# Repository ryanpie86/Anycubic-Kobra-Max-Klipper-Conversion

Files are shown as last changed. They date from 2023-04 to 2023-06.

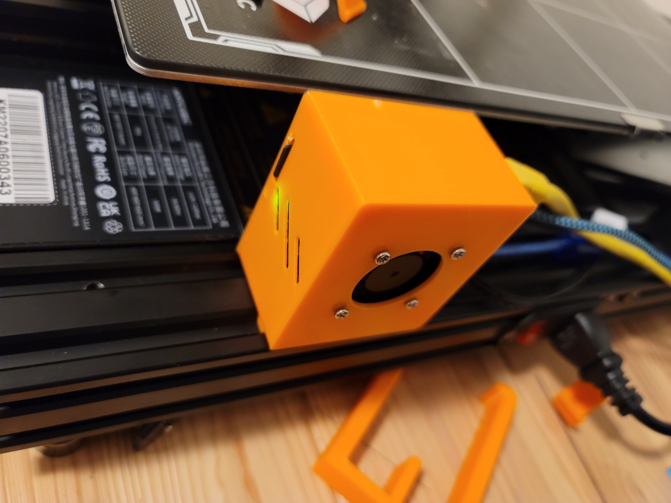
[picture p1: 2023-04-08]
20230408_024842.jpg

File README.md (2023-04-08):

# Anycubic-Kobra-Max-Klipper-Conversion

**You will need to remove resistor R66 on your circuit board and place it in R65 spot.**
**Please see https://www.reddit.com/r/anycubic/comments/ynvbj0/anycubic_kobra_working_config for detailed information**

The printer this has been configured for is stock minus just some Capricorn tubing (and of course the Klipper conversion)

I have tried to credit everyone for the information I have gathered in the printer.cfg. If you feel I have missed something, please do say so.

Also uploaded is a Cura project file containing my optimized 0.2 PLA+ slicer profile, and of course a Cali Cat sitting in it. Import the project into Cura as a new profile.

Oh, and no, your screen will not work after this. After you flash and get the 4 beeps the screen will freeze. Wait a few seconds, power the machine off, and then disconnect the screen. You won't be needing that where you're headed.

Join the discussion here: https://www.reddit.com/r/anycubic/comments/12a2fqp/any_interest_in_a_kobra_max_klipper_package/

This printer.cfg has print area mesh enabled by default. You just need to follow the steps outlined in the notes for the macro if you are using Cura, or follow the link contained to set up a different slicer.

From messing with it and the strain gauge, I found that the device Anycubic chose is inaccurate if not A) hot and B) heated at least to print temperature. There are two problems:
**
1. the extruder tension changes when the filament inside is cold/tugging on it while moving around

2. any little bit of solid plastic on the nozzle tip will ruin what you had previously set for z-offset after the mesh is complete.**

My config is optimized for this. You can home the printer cold just to get it ready if you want, but the START_PRINT macro makes up for it. It will heat, clear the mesh, re-home HOT, mesh the print area, then load the mesh and begin. I am getting very good results with this method so far, and have put quite a bit of time into making it work right. I've been able to set a hard z-offset and not play with it thus far.

Changed microsteps for X/Y to 64 as per invisiblek:

https://github.com/invisiblek/klipper_config/tree/kobraplus

This seems to have fixed Y axis layer shifting.

Added load/unload filament macros. Do not use these while printing, it will turn off your heaters and LEDs and change the temperature.

Added my model for an Orange Pi Zero 2 enclosure which will fit the frame rail behind the screen. This enclosure accomodates having a fan attached to the inside for a clean look.

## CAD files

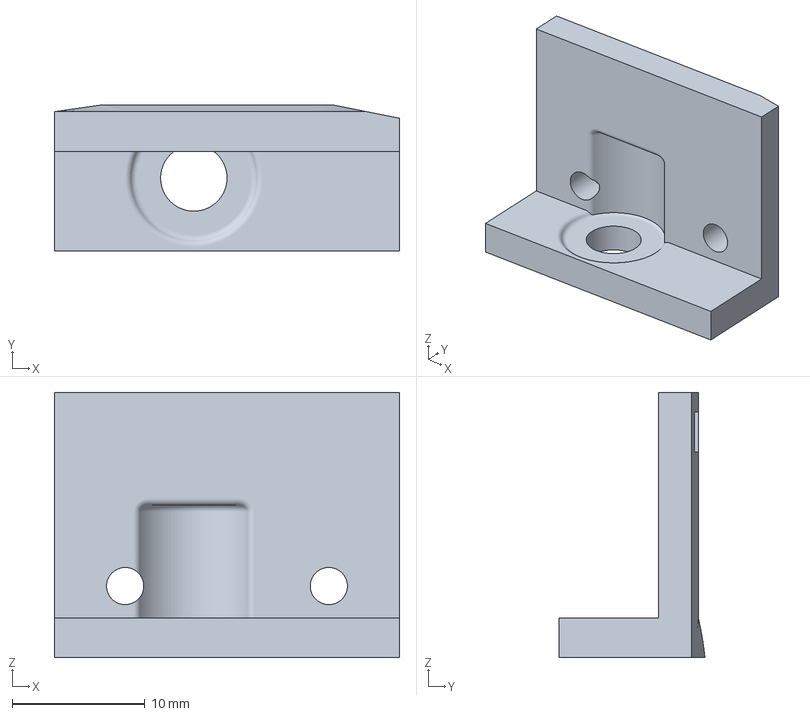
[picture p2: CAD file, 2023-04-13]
Kobra_ADXL345 v7.3mf
26.0 x 11.0 x 20.0 mm

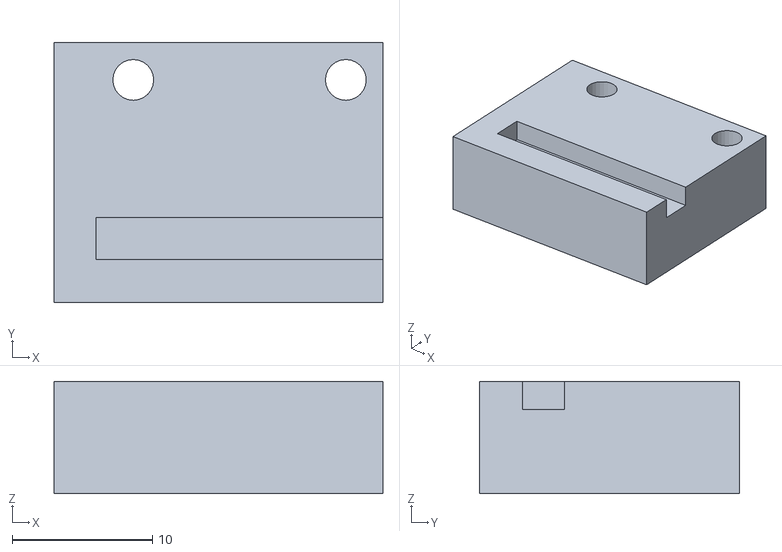
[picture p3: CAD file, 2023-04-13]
adxl345_bedPrint.stl
23.5 x 18.5 x 8.00

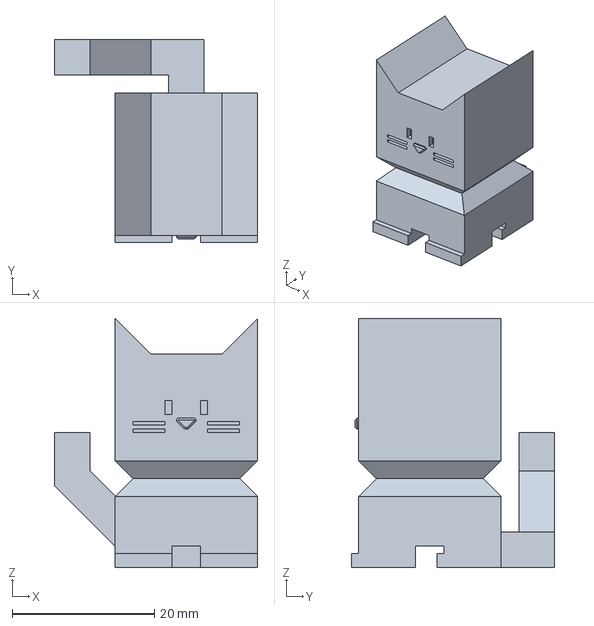
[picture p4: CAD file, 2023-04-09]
AKMAX_calicat.3mf
28.5 x 28.5 x 35.0 mm

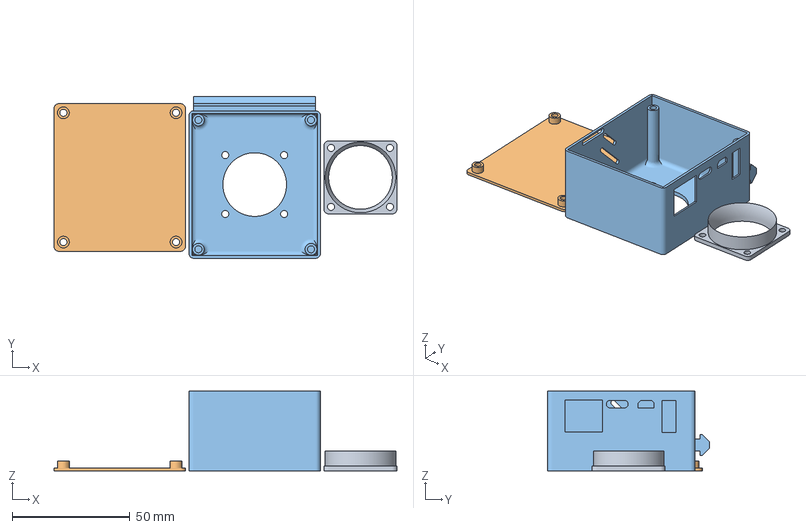
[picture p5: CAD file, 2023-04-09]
oPiZero2EnclosureWithFanShroud.3mf
145.6 x 68.6 x 33.8 mm
OrangePi_Zero_2 v14_dwg v13.3mf
oPiBottomCover.3mf
oPiTopCover.3mf

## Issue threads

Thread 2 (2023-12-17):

Start_macro doesnt start the print after calibration

namalahideaway, 2023-12-17:
The start_macro calibrates and then print is paused. You need to manually resume the print once the calibration is done.

Have cura python and start macro enabled.

not sure what the issue is.

If i use defauly cura macro it works... but using the start_macro in the macros.cfg it pauses.

ryanpie86, 2023-12-17:
It pauses to purge and clean the nozzle. You can remove the pause line from
the start_print macro in macros.cfg.

On Sat, Dec 16, 2023, 9:31 PM namalahideaway ***@***.***>
wrote:

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

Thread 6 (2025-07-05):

Current for the Z steppers

50koruny, 2025-07-05:
Good job.Thank you for this.
It helped me a lot.
Anyway, there is a 0.9A current for the Z stepper driver.
There are two steppers connected to that driver in parallel connection, so with 0.9A, every stepper will only get 0,45A of current, which is low.
I just wanted to say this...
But overally, this config is a good reference to get Klipper to Kobra Max.

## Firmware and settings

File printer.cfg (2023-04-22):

## Anycubic Kobra Max ##
## Compile for HC32F460 ##
## Serial PA3 & PA2 "Anycube"

[include mainsail.cfg]
[include macros.cfg]

[mcu]
serial: /dev/serial/by-id/usb-1a86_USB_Serial-if00-port0
restart_method: command
baud: 250000

### Enable this to use the Orange Pi as MCU.
### I haven't found anything useful for this yet as nothing works for SPI on it
#[mcu opi]
#serial: /tmp/klipper_host_mcu

### Enable this to use an RP2040 for your ADXL host. You cannot use the Orange Pi so this is the next best option.
#[mcu adxl]
# Change <mySerial> to whatever you found above. For example,
# usb-Klipper_rp2040_E661640843545B2E-if00
#serial: /dev/serial/by-id/usb-Klipper_rp2040_E660C062137B4E29-if00
#[adxl345]
#cs_pin: adxl:gpio1
#spi_bus: spi0a
#axes_map: x,z,y
#[resonance_tester]
#accel_chip: adxl345
#    203.5, 200, 20
#[output_pin power_mode] # Improve power stability
#pin: adxl:gpio23

[stepper_x]
step_pin: PA5
dir_pin: PA4
enable_pin: !PC3
microsteps: 64
rotation_distance: 40
endstop_pin: !PA6
position_min: -6
position_endstop: -5
position_max: 407
homing_speed: 100

[tmc2209 stepper_x]
uart_pin:PA15
tx_pin:PA9
#diag_pin:PA6
sense_resistor: 0.100
run_current: 0.9
uart_address: 3
#driver_SGTHRS: 0
interpolate: False
stealthchop_threshold: 999999

[stepper_y]
step_pin: PC4
dir_pin: PA7
enable_pin: !PC3
microsteps: 64
rotation_distance: 40
endstop_pin: !PC5
position_min: -23.3
position_endstop: -23.2
position_max: 400
homing_speed: 100

[tmc2209 stepper_y]
uart_pin:PA15
tx_pin:PA9
#diag_pin:^PC5
sense_resistor: 0.100
run_current: 1
uart_address: 1
#driver_SGTHRS: 50
interpolate: False
#stealthchop_threshold: 999999

### Don't forget to SET YOUR E-STEPS!
### Measure 120mm, then extrude 100mm
### G1 E100 F100
### step_distance = old_e_steps * ((120 - distance_to_mark) / 100)

[extruder]
max_extrude_only_distance: 100.0
step_pin: PC14
dir_pin: !PC15
enable_pin: !PC3
microsteps: 16
#rotation_distance: 7.71 #For stock extruder (To be calibrated !)
rotation_distance: 7.21
nozzle_diameter: 0.800
filament_diameter: 1.750
heater_pin: PA1
sensor_type: EPCOS 100K B57560G104F
sensor_pin: PC1
min_temp: 0
max_temp: 250
pressure_advance: 0.6

[tmc2208 extruder]
uart_pin:PA15
tx_pin:PA9
#diag_pin:PB7
sense_resistor: 0.100
run_current: 0.9
uart_address: 0
#stealthchop_threshold: 999999

[stepper_z]
step_pin: PC7
dir_pin: !PC6
enable_pin: !PC3
microsteps: 16
rotation_distance: 8
endstop_pin: probe:z_virtual_endstop
#endstop_pin: PA8
#position_endstop: 0
position_min: -20
position_max: 452
homing_speed: 5

[tmc2209 stepper_z]
uart_pin:PA15
tx_pin:PA9
#diag_pin:PA8
sense_resistor: 0.100
run_current: 0.9
uart_address: 2
#driver_SGTHRS: 0
stealthchop_threshold: 999999

[stepper_z1]
step_pin: PB1
dir_pin: !PB0
enable_pin: !PC3
microsteps: 16
rotation_distance: 8

[probe]
pin: !PB6
speed: 2.5
samples: 3
samples_tolerance_retries: 3
#z_offset: 0.05
activate_gcode: probe_reset
### This macro is needed to reset the factory strain gauge on the Kobra Max
[gcode_macro probe_reset]
gcode:
    SET_PIN PIN=probe_reset_pin VALUE=1
    G4 P500
    SET_PIN PIN=probe_reset_pin VALUE=0
    G4 P100

[output_pin probe_reset_pin]
pin: !PB7

[safe_z_home]
home_xy_position: 203.5, 200 # Center of bed
speed: 100
z_hop: 5               # Move up 5mm
z_hop_speed: 20
move_to_previous: False

[bed_mesh]
speed: 100
horizontal_move_z: 3
mesh_min: 19, 19
mesh_max: 380, 380
algorithm: bicubic
probe_count: 5, 5

[output_pin LED]
pin: mcu:PB8
pwm: False
value: 0

[heater_bed]
heater_pin: PA0
sensor_type: EPCOS 100K B57560G104F
sensor_pin: PC0
#control = pid
#pid_kp = 73.966
#pid_ki = 0.884
#pid_kd = 1547.747
min_temp: 0
max_temp: 130

[fan]
pin: PB9

[heater_fan hotend_fan]
pin: PA13
heater: extruder
heater_temp: 50.0

[heater_fan controller_fan]
pin: PA14
heater: heater_bed
heater_temp: 45.0

[filament_switch_sensor runout]
pause_on_runout: True
switch_pin: !PC13

[temperature_sensor pi_temp]
sensor_type: temperature_host
min_temp: 0
max_temp: 100

[printer]
kinematics: cartesian
max_velocity: 300
max_accel: 2500
max_z_velocity: 5
max_z_accel: 100


#*# <---------------------- SAVE_CONFIG ---------------------->
#*# DO NOT EDIT THIS BLOCK OR BELOW. The contents are auto-generated.
#*#
#*# [heater_bed]
#*# control = pid
#*# pid_kp = 69.538
#*# pid_ki = 0.893
#*# pid_kd = 1353.388
#*#
#*# [extruder]
#*# control = pid
#*# pid_kp = 28.130
#*# pid_ki = 1.875
#*# pid_kd = 105.487
#*#
#*# [probe]
#*# z_offset = -0.110
#*#
#*# [input_shaper]
#*# shaper_type_x = mzv
#*# shaper_freq_x = 68.2
#*# shaper_type_y = mzv
#*# shaper_freq_y = 33.4

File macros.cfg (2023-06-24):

[gcode_macro LOAD_FILAMENT]
gcode:
    SET_HEATER_TEMPERATURE HEATER=extruder TARGET=210
    M109 S210
    SET_PIN PIN=LED VALUE=1.00
    M83
    G0 E10 F60
    M83
    G0 E100 F600
    M83
    G0 E100 F600
    SET_HEATER_TEMPERATURE HEATER=extruder TARGET=210
    M83
    G0 E100 F300
    M83
    G0 E100 F300
    SET_HEATER_TEMPERATURE HEATER=extruder TARGET=210
    M83
    G0 E100 F300
    M83
    G0 E100 F300
    SET_HEATER_TEMPERATURE HEATER=extruder TARGET=0
    SET_PIN PIN=LED VALUE=0.00

[gcode_macro UNLOAD_FILAMENT]
gcode:
    M109 S210
    SET_PIN PIN=LED VALUE=1.00
    M83
    G0 E-50 F60
    M83
    G0 E-50 F300
    M83
    G0 E-100 F600
    M83
    G0 E-100 F600
    M83
    G0 E-100 F600
    M83
    G0 E-100 F600
    TURN_OFF_HEATERS
    SET_PIN PIN=LED VALUE=0.00

#     In CURA use the following machine Start GCODE:
#
#     START_PRINT EXTRUDER_TEMP={material_print_temperature_layer_0} BED_TEMP={material_bed_temperature_layer_0} AREA_START=%MINX%,%MINY% AREA_END=%MAXX%,%MAXY%
#
#     If you want to edit your Start Print GCODE, do it in this configuration instead.

[gcode_macro START_PRINT]
gcode:
    G28; Home
    G1 X1 Y1 Z1; go to center while heating up
    G1 Z0.1 F600; lower Z to bed so blob will stick to it
    {% set BED_TEMP = params.BED_TEMP|default(60)|float %}
    {% set EXTRUDER_TEMP = params.EXTRUDER_TEMP|default(190)|float %}
    # Start bed heating (but don't wait for it)
    M140 S{BED_TEMP}
    # Use absolute coordinates
    G90
    # Wait for bed to reach temperature
    M190 S{BED_TEMP}
    # Set and wait for nozzle to reach temperature
    M109 S{EXTRUDER_TEMP}
    BED_MESH_CLEAR
    BED_MESH_PROFILE REMOVE="default"
    G28 Z; recalibrate Z now that we are at temp
    Z_TILT_ADJUST
    BED_MESH_CALIBRATE AREA_START={params.AREA_START|default("0,0")} AREA_END={params.AREA_END|default("0,0")}
    BED_MESH_PROFILE LOAD="default"
    PAUSE
    SET_PIN PIN=LED VALUE=1.00
    G0 E25 F2700; spit out a pile of goo into the corner

###     In CURA use the following machine End GCODE:
###
#     END_PRINT
###
###     If you want to edit your End Print GCODE, do it in this configuration instead.

[gcode_macro END_PRINT]
gcode:
    G91
    #turn off heaters
    M106 S0
    M104 S0
    M140 S0
    G0 E-7 F2700; retract 7mm
    G1 E-2 Z0.2 F2400; retract 2mm more and raise Z by one layer
    G1 X5 Y5 F3000; move over 5mm for a wipe
    G1 Z10; raise Z by 10
    G90
    G1 X10 Y400; present the print
    M84 X Y E; turn off all the steppers but Z
    #turn off the light
    SET_PIN PIN=LED VALUE=0.00

[gcode_macro DO_A_MESH]
gcode:
    #unload the existing mesh profile
    BED_MESH_CLEAR
    M140 S60; PREHEAT bed
    M109 S175; PREHEAT nozzle
    #clear the existing mesh out 
    BED_MESH_PROFILE REMOVE="default"
    M190 S60;  Wait for bed to reach temperature
    M109 S215; Set and wait for nozzle to reach temperature
    G28; home axes
    Z_TILT_ADJUST
    #perform a standard full-bed mesh level
    BED_MESH_CALIBRATE_BASE


### This macro is to mesh only the area of the bed which will be printed on
### In order to take advantage of this option, there is further work you will need to do in your slicer software
### If you do not use Cura, please visit the following link to finish setting this up:
#
#                 https://gist.github.com/ChipCE/95fdbd3c2f3a064397f9610f915f7d02
#
### If you DO use Cura, I have already taken most steps for you. Please visit the following link to download the post processing plugin. Save this text as KlipperPrintArea.py.
#
#                 https://raw.githubusercontent.com/ChipCE/Slicer-profile/master/cura-slicer/scripts/KlipperPrintArea.py
#
### In cura menu Help -> Show configuration folder. - Copy the python script from the above link in to scripts folder. - Restart Cura - In cura menu Extensions ->
### Post processing -> Modify G-Code and select Klipper print area mesh


[gcode_macro BED_MESH_CALIBRATE]
rename_existing: BED_MESH_CALIBRATE_BASE
; gcode parameters
variable_parameter_AREA_START : 0,0
variable_parameter_AREA_END : 0,0
; the clearance between print area and probe area 
variable_mesh_area_offset : 5.0
; number of sample per probe point
variable_probe_samples : 2
; minimum probe count
variable_min_probe_count : 4
; scale up the probe count, should be 1.0 ~ < variable_max_probe_count/variable_min_probe_count
variable_probe_count_scale_factor : 1.0
; enable preference index
variable_enable_reference_index : False
gcode:
    {% if params.AREA_START and params.AREA_END %}
        {% set bedMeshConfig = printer["configfile"].config["bed_mesh"] %}
        {% set safe_min_x = bedMeshConfig.mesh_min.split(",")[0]|float %}
        {% set safe_min_y = bedMeshConfig.mesh_min.split(",")[1]|float %}
        {% set safe_max_x = bedMeshConfig.mesh_max.split(",")[0]|float %}
        {% set safe_max_y = bedMeshConfig.mesh_max.split(",")[1]|float %}

        {% set area_min_x = params.AREA_START.split(",")[0]|float %}
	{% set area_min_y = params.AREA_START.split(",")[1]|float %}
	{% set area_max_x = params.AREA_END.split(",")[0]|float %}
	{% set area_max_y = params.AREA_END.split(",")[1]|float %}

	{% if bedMeshConfig.probe_count.split(",")|length == 2 %}
            {% set meshPointX = bedMeshConfig.probe_count.split(",")[0]|int %}
            {% set meshPointY = bedMeshConfig.probe_count.split(",")[1]|int %}
        {% else %}
            {% set meshPointX = bedMeshConfig.probe_count.split(",")[0]|int %}
            {% set meshPointY = bedMeshConfig.probe_count.split(",")[0]|int %}
        {% endif %}

	{% set meshMaxPointX = meshPointX %}
	{% set meshMaxPointY = meshPointY %}


        {% if (area_min_x < area_max_x) and (area_min_y < area_max_y) %}
            {% if area_min_x - mesh_area_offset >=  safe_min_x %}
                {% set area_min_x = area_min_x - mesh_area_offset %}
            {% else %}
                {% set area_min_x = safe_min_x %}
            {% endif %}

            {% if area_min_y - mesh_area_offset >=  safe_min_y %}
                {% set area_min_y = area_min_y - mesh_area_offset %}
            {% else %}
                {% set area_min_y = safe_min_y %}
            {% endif %}

            {% if area_max_x + mesh_area_offset <=  safe_max_x %}
                {% set area_max_x = area_max_x + mesh_area_offset %}
            {% else %}
                {% set area_max_x = safe_max_x %}
            {% endif %}

            {% if area_max_y + mesh_area_offset <=  safe_max_y %}
                {% set area_max_y = area_max_y + mesh_area_offset %}
            {% else %}
                {% set area_max_y = safe_max_y %}
            {% endif %}

            {% set meshPointX = (meshPointX * (area_max_x - area_min_x) / (safe_max_x - safe_min_x) * probe_count_scale_factor)|round(0)|int %}
            {% if meshPointX < min_probe_count %}
                {% set meshPointX = min_probe_count %}
            {% endif %}
	    {% if meshPointX > meshMaxPointX %}
                {% set meshPointX = meshMaxPointX %}
            {% endif %}

            {% set meshPointY = (meshPointY * (area_max_y -area_min_y ) / (safe_max_y - safe_min_y) * probe_count_scale_factor )|round(0)|int %}
            {% if meshPointY < min_probe_count %}
                {% set meshPointY = min_probe_count %}
            {% endif %}
	    {% if meshPointY > meshMaxPointY %}
                {% set meshPointY = meshMaxPointY %}
            {% endif %}

            {% set algorithm = "bicubic" %}
	    {% if "algorithm" in bedMeshConfig %}
	        {% set algorithm = bedMeshConfig.algorithm %}
            {% endif %}
            {% if meshPointX >=7 or meshPointY >=7 %}
                {% set algorithm = "bicubic" %}
            {% endif %}

            {% if enable_reference_index %}
                {% set referenceIndex = (meshPointX * meshPointY / 2 - 1 )|round(0)|int %}
                BED_MESH_CALIBRATE_BASE mesh_min={area_min_x},{area_min_y} mesh_max={area_max_x},{area_max_y} probe_count={meshPointX},{meshPointY} samples={probe_samples|int} algorithm={algorithm} relative_reference_index={referenceIndex}
            {% else %}
                BED_MESH_CALIBRATE_BASE mesh_min={area_min_x},{area_min_y} mesh_max={area_max_x},{area_max_y} probe_count={meshPointX},{meshPointY} samples={probe_samples|int} algorithm={algorithm}
            {% endif %}
        {% else %}
            BED_MESH_CALIBRATE_BASE
        {% endif %}
    {% else %}
        BED_MESH_CALIBRATE_BASE
    {% endif %}
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

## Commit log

2023-04-04 Add files via upload
    Compiled 3 April 2023 using Klipper v0.11.0-159-gfec7ddd8
2023-04-04 Add files via upload
    Current Cura 5.3.0 profile for 0.2 layer PLA+. File also includes a Cali Cat (https://www.thingiverse.com/thing:1545913)
    [AKMAX_calicat.3mf]
2023-04-04 Update printer.cfg
    Disabled stealthchop for Z to troubleshoot some TMC temperature errors
    Increased X/Y min by -0.1 to avoid out of range error when homing
    [printer.cfg]
2023-04-04 Update printer.cfg
    Reorganized some things, fixed an odd error where Z would not home if M84 happens above ~10mm high.
    [printer.cfg]
2023-04-04 Update printer.cfg
    Work on START_PRINT and attempt to get rid of blob
    [printer.cfg]
2023-04-05 https://github.com/invisiblek/klipper_config/tree/kobraplus
    Change interpolation values and microsteps for X/Y, disable stealthchop. Please see link for more information. Am currently experiencing severe Y axis shift.
    [printer.cfg]
2023-04-06 https://ellis3dp.com/Print-Tuning-Guide/articles/determining_max_speeds_accels.html
    Losing steps w/ 150@5000, iffy at 200/4000, so settled on 150/4000. I doubt this printer is ever going to hit 150mm/s speed anyway. The bed is just far too heavy.
    [printer.cfg]
2023-04-08 Update printer.cfg
    Added load and unload filament macros to simulate factory controls, only better. You don't need to keep an eye on it. Press the button and it will wait to heat (to a much lower temperature), turn on 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
    [printer.cfg]
2023-04-09 Update printer.cfg
    Pressure advance and basic resonance compensation working. Orange Pi Zero MCU working but still no SPI for ADXL. Will have to do a Pico for this. Increased Y current to 1.0
    [printer.cfg]
2023-04-13 Update printer.cfg
    Clean up cfg, add ADXL information and the resonances for my particular printer. Make separate file for macros because they were crowding the cfg.
    [printer.cfg]
2023-04-13 Add files via upload
    All of the macros I use
    [macros.cfg]
2023-04-13 Add files via upload
    ADXL mounts that will work for the Kobra Max
    [Kobra_ADXL345 v7.3mf, adxl345_bedPrint.stl]
2023-04-22 Update macros.cfg
    The default timeout was preventing the load filament macro from completing without issues. This fixed it.
    [macros.cfg]
